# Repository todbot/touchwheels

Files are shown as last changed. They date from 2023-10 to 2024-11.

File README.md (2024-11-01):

# Touchwheels

Some capacitive sense rotary touchwheels.  

These work by using only three capactive touch pads in a specific interleaved 
geometry and measuring the relative ratio of analog capacitive touch values 
between the pads to compute a distance along the slider. 

### Touchwheels made so far:

* TouchWheelSAO -- [Touchwheel SAO as part of  Hackaday Supercon 2024 badge](https://github.com/todbot/TouchwheelSAO)

* touchwheel0 - [available on Tindie as a kit!](https://www.tindie.com/products/todbot/touchwheel0-capacitive-touch-wheel/)

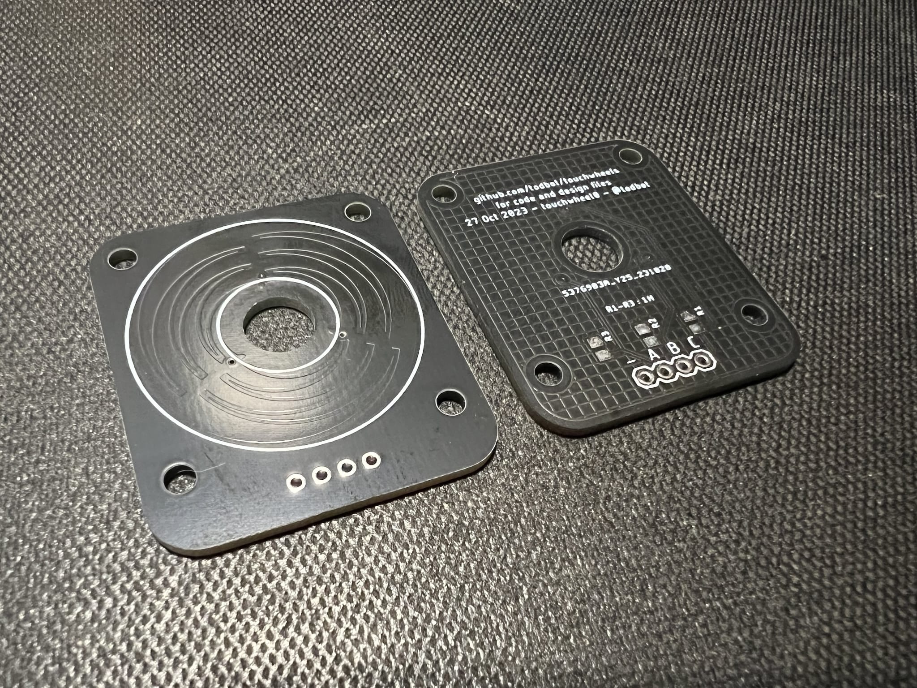
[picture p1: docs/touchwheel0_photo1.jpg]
  
  
  Similar to an iPod's wheel, `touchwheel0` is a 30 mm (0.6") diameter 
  [rotary capacitive touch slider](https://onlinedocs.microchip.com/pr/GUID-A8A0085D-58D1-4E41-A07D-B93BFDE11AFE-en-US-4/index.html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) that can be used with most any microcontroller. It uses three digital GPIO pins and requires no extra components. The included examples in CircuitPython and Arduino show how to turn the raw capacitive touch readings of the three pins into a linear 0-360º angle measurement.

* picoslidertoy - Available at the [picoslidertoy repo](https://github.com/todbot/picoslidertoy)
  
  

### Demos:

There are several examples on how to use the touchwheel:

- [demo0](./circuitpython/demo0/code.py) -
    CircuitPython example showing basic concept on touchwheel0
  
- [touchwheel_badgedemo](./circuitpython/touchwheel_badgedemo/code.py) - 
    CircuitPython example for the Hackaday SuperCon 2023 badge (where touchwheel0 PCBs were given away)
    
- [demo_dual](./circuitpython/demo_dual/code.py) - 
    CircuitPython example show two touchwheel0s in use

- more demos coming!

### What's in Tindie touchwheel0 kit: 

The [touchwheel0 kit](https://www.tindie.com/products/todbot/touchwheel0-capacitive-touch-wheel/)
on Tindie comes with:

- touchwheel0 black PCB
- 4 x 1M 0805 SMD resistors (only three needed, one is a spare)
- 1 x 4-pin pin header 

It makes a pretty good "first SMD soldering" exercise as the 0805 resistors 
are relatively big and not very heat sensitive. 

### Demo videos:

- demo dual:
  [(click to view on youtube)](https://www.youtube.com/watch?v=Db7S75eE-G8)

  [](https://www.youtube.com/watch?v=Db7S75eE-G8 "touchwheel0 dual demo")

- demo0: 

  https://github.com/todbot/touchwheels/assets/274093/fc2b794f-5dff-42b4-8942-f141de19e4ab

### Useful links:

- [AN2934 - Capacitive Touch Sensor Design Guide (pdf)](https://ww1.microchip.com/downloads/en/Appnotes/Capacitive-Touch-Sensor-Design-Guide-DS00002934-B.pdf)
- [QTAN007 - Buttons, Sliders and Wheels - Sensor Design Guide (pdf)](https://www.mouser.com/pdfDocs/QTouch_QTAN0079.pdf)
- [AT02259: QTouch Schematic and Layout Checklist (pdf)](http://ww1.microchip.com/downloads/en/appnotes/atmel-42094-qtouch-schematic-and-layout-checklist_applicationnote_at02259.pdf)
- [slider generator](https://cooltech.zone/tangara/labs/touchwheel-electrode-tool/)
- [SLAA891B: Automating Capacitive Touch Sensor PCB layouts with OpenSCAD Ti AppNote (pdf)](https://www.ti.com/lit/an/slaa891b/slaa891b.pdf?ts=1725369981627)

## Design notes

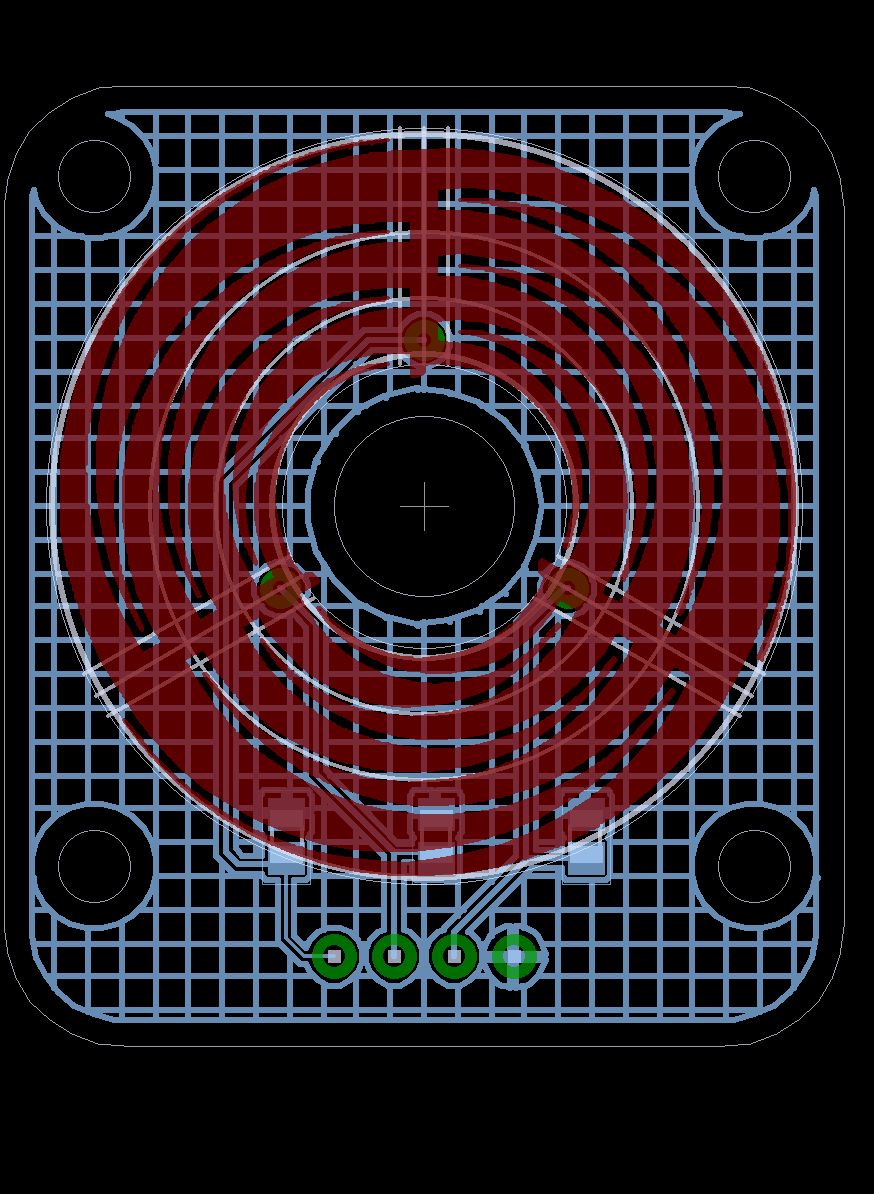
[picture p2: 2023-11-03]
hardware/touchwheel0/touchwheel0_pcb.png

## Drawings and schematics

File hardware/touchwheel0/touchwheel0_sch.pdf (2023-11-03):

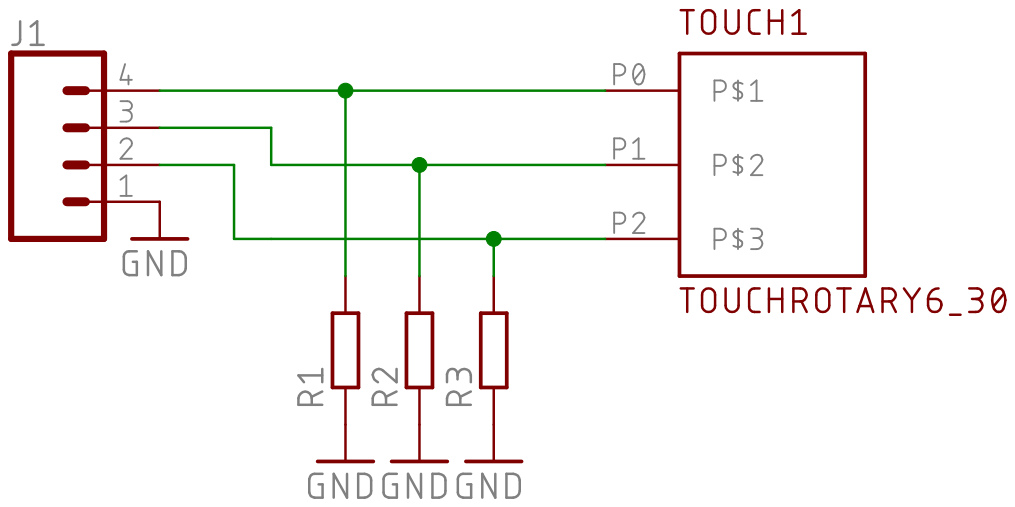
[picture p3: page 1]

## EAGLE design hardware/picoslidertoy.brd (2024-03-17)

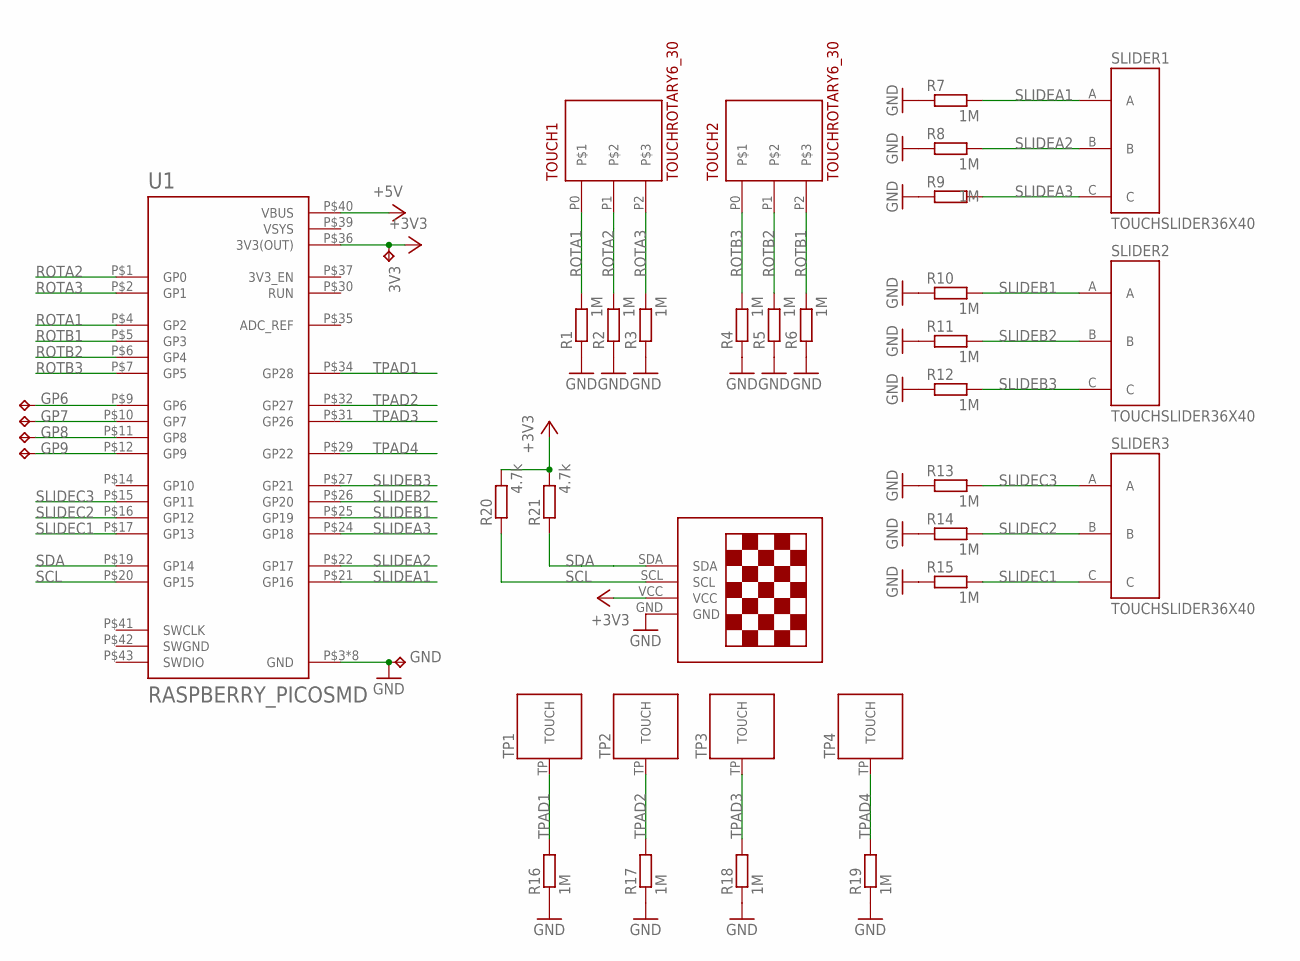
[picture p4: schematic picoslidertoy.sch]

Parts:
3V3: TPTP20R; TP20R
GND: TPTP20R; TP20R
GP6, GP7, GP8, GP9: TPTP20R; TP20R
R1, R2, R3, R4, R5, R6, R7, R8, R9, R10, R11, R12, R13, R14, R15, R16, R17, R18, R19: 1M; R0805
R20, R21: 4.7k; R0805
SLIDER1, SLIDER2, SLIDER3: TOUCHSLIDER36X40; TOUCHSLIDER3_6X40
SMDBACK2: 13"OLEDSMDONLY; 1.3"OLED_SMDBACKONLY
TOUCH1, TOUCH2: TOUCHROTARY6_30; TOUCHROTARY1B
TP1, TP2, TP3, TP4: TOUCHPADA; TOUCHPADA_0.5IN
U1: RASPBERRY_PICOSMD; PICO-PKG-SMD

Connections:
+3V3: 3V3.TP, R20.2, R21.2, SMDBACK2.VCC, U1.P$36 (3V3(OUT))
+5V: U1.P$40 (VBUS)
GND: GND.TP, R1.1, R2.1, R3.1, R4.1, R5.1, R6.1, R7.1, R8.1, R9.1, R10.1, R11.1, R12.1, R13.1, R14.1, R15.1, R16.1, R17.1, R18.1, R19.1, SMDBACK2.GND, U1.P$3 (GND), U1.P$8 (GND), U1.P$13 (GND), U1.P$18 (GND), U1.P$23 (GND), U1.P$28 (GND), U1.P$33 (GND), U1.P$38 (GND)
unnamed: GP6.TP, U1.P$9 (GP6)
unnamed: GP7.TP, U1.P$10 (GP7)
unnamed: GP9.TP, U1.P$12 (GP9)
unnamed: GP8.TP, U1.P$11 (GP8)
ROTA1: R1.2, TOUCH1.P0, U1.P$4 (GP2)
ROTA2: R2.2, TOUCH1.P1, U1.P$1 (GP0)
ROTA3: R3.2, TOUCH1.P2, U1.P$2 (GP1)
ROTB1: R6.2, TOUCH2.P2, U1.P$5 (GP3)
ROTB2: R5.2, TOUCH2.P1, U1.P$6 (GP4)
ROTB3: R4.2, TOUCH2.P0, U1.P$7 (GP5)
SCL: R20.1, SMDBACK2.SCL, U1.P$20 (GP15)
SDA: R21.1, SMDBACK2.SDA, U1.P$19 (GP14)
SLIDEA1: R7.2, SLIDER1.A, U1.P$21 (GP16)
SLIDEA2: R8.2, SLIDER1.B, U1.P$22 (GP17)
SLIDEA3: R9.2, SLIDER1.C, U1.P$24 (GP18)
SLIDEB1: R10.2, SLIDER2.A, U1.P$25 (GP19)
SLIDEB2: R11.2, SLIDER2.B, U1.P$26 (GP20)
SLIDEB3: R12.2, SLIDER2.C, U1.P$27 (GP21)
SLIDEC1: R15.2, SLIDER3.C, U1.P$17 (GP13)
SLIDEC2: R14.2, SLIDER3.B, U1.P$16 (GP12)
SLIDEC3: R13.2, SLIDER3.A, U1.P$15 (GP11)
SWGND: U1.P$42 (SWGND)
TPAD1: R16.2, TP1.TP, U1.P$34 (GP28)
TPAD2: R17.2, TP2.TP, U1.P$32 (GP27)
TPAD3: R18.2, TP3.TP, U1.P$31 (GP26)
TPAD4: R19.2, TP4.TP, U1.P$29 (GP22)
VSYS: U1.P$39 (VSYS)

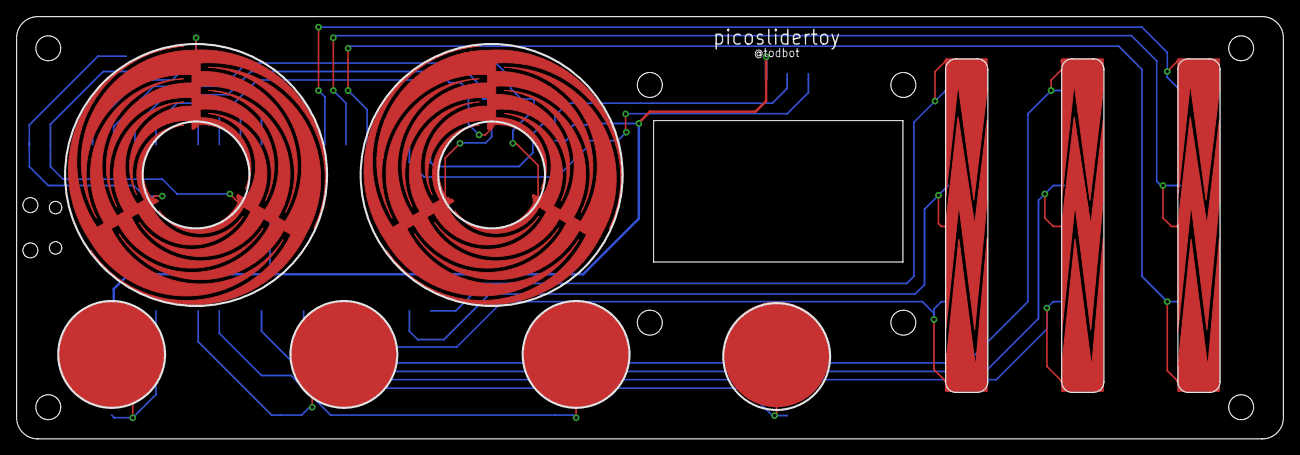
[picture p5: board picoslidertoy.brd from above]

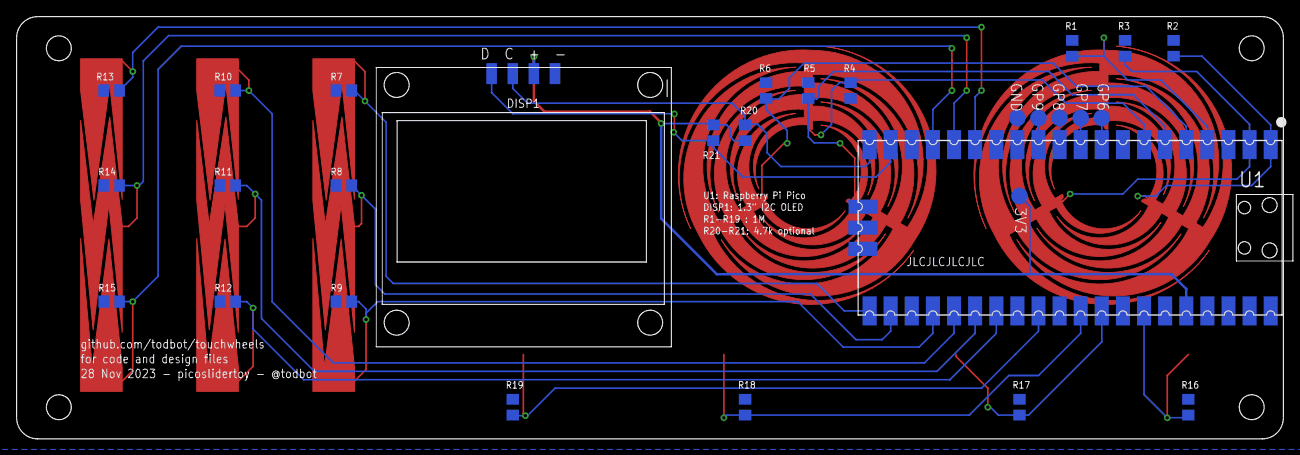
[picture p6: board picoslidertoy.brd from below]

Board: 2 copper layers, 152.4 x 50.8 mm, 38 parts (28 on the bottom side), 27 nets.

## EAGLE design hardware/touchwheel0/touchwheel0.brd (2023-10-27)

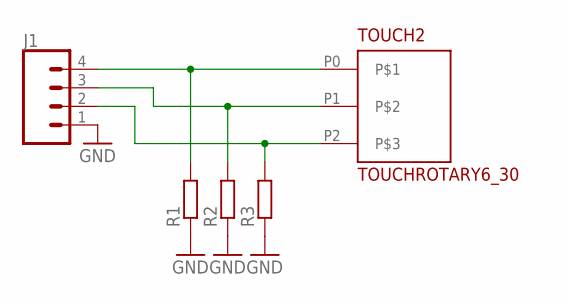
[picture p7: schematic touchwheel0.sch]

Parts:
J1: CONN_04; 1X04
R1, R2, R3: R-EU_R0805; R0805
TOUCH2: TOUCHROTARY6_30; TOUCHROTARY1B

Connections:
GND: J1.1, R1.1, R2.1, R3.1
unnamed: J1.4, R1.2, TOUCH2.P0
unnamed: J1.3, R2.2, TOUCH2.P1
unnamed: J1.2, R3.2, TOUCH2.P2

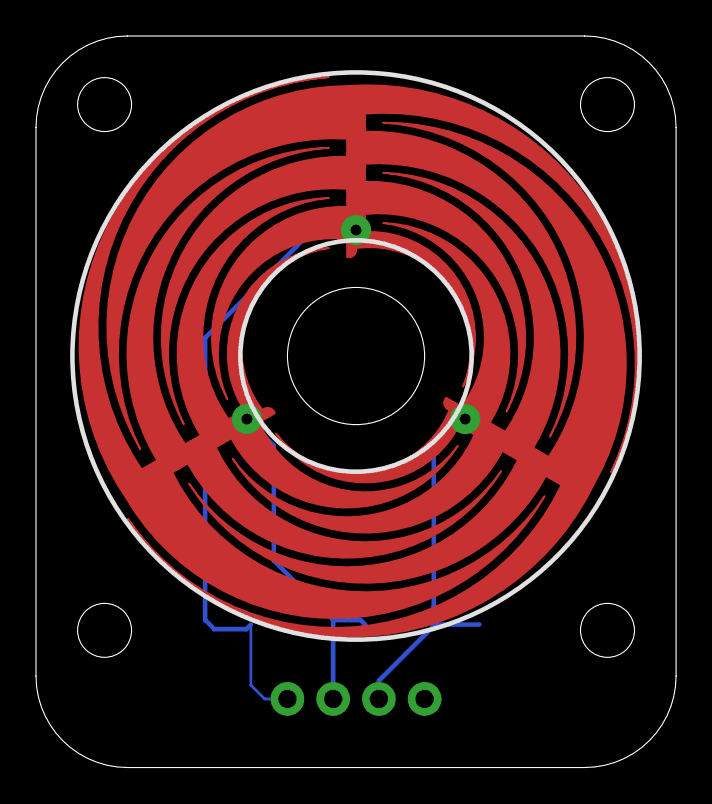
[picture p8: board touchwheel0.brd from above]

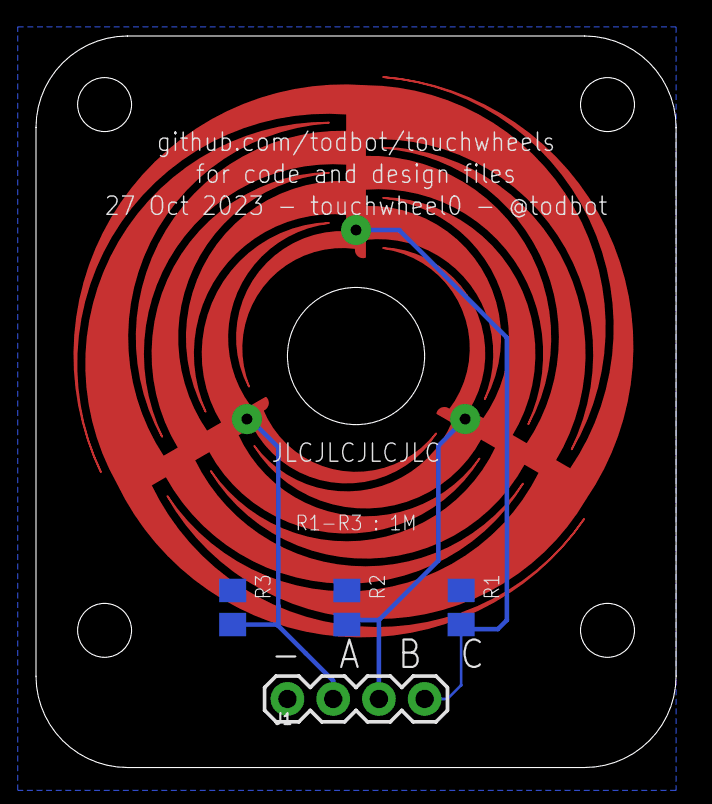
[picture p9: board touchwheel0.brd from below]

Board: 2 copper layers, 35.6 x 40.6 mm, 5 parts (4 on the bottom side), 4 nets.

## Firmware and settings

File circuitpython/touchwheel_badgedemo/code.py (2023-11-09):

# touchwheel_badgedemo.py -- try out touchwheel on Supercon2023 badge in CircuitPython
# 5 Nov 2023 - @todbot / Tod Kurt
#  originally from github.com/todbot/HackadayVectorscopeHacks
#
import time, math
import board
import touchio

# touchwheel plugged into GND,GP26,GP27,GP28 on side of Supercon2023 badge
touch_pins = (board.GP26, board.GP27, board.GP28)

class TouchWheel():
    """Simple capacitive touchweel made from three captouch pads """
    def __init__(self,touch_pins, offset=-0.333/2):
        self.touchins = []
        self.offset = offset # physical design is rotated 1/2 a sector anti-clockwise
        for p in touch_pins:
            touchin = touchio.TouchIn(p)
            self.touchins.append(touchin)

    def pos(self):
        """
        Given three touchio.TouchIn pads, compute wheel position 0-1
        or return None if wheel is not pressed
        """
        a = self.touchins[0]
        b = self.touchins[1]
        c = self.touchins[2]

        # compute raw percentages
        a_pct = (a.raw_value - a.threshold) / a.threshold
        b_pct = (b.raw_value - b.threshold) / b.threshold
        c_pct = (c.raw_value - c.threshold) / c.threshold
        #print( "%+1.2f  %+1.2f  %+1.2f" % (a_pct, b_pct, c_pct), end="\t")

        pos = None
        # cases when finger is touching two pads
        if a_pct >= 0 and b_pct >= 0:  #
            pos = 0 + 0.333 * (b_pct / (a_pct + b_pct))
        elif b_pct >= 0 and c_pct >= 0:  #
            pos = 0.333 + 0.333 * (c_pct / (b_pct + c_pct))
        elif c_pct >= 0 and a_pct >= 0:  #
            pos = 0.666 + 0.333 * (a_pct / (c_pct + a_pct))
        # special cases when finger is just on a single pad.
        elif a_pct > 0 and b_pct <= 0 and c_pct <= 0:
            pos = 0
        elif a_pct <= 0 and b_pct > 0 and c_pct <= 0:
            pos = 0.333
        elif a_pct <= 0 and b_pct <= 0 and c_pct > 0:
            pos = 0.666
        # wrap pos around the 0-1 circle if offset puts it outside that range
        return (pos + self.offset) % 1 if pos is not None else None


touchwheel = TouchWheel(touch_pins)

while True:
    pos = touchwheel.pos()
    if pos is not None:   # touched!
        print("touch_pos:", pos)
    else:
        print("no touch")
    time.sleep(0.05)

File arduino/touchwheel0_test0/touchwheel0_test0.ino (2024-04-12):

// touchwheel0_test0.ino -- initial demonstration of touchwheel on Arduino, needs work still
// 2 Apr 2024 - @todbot / Tod Kurt

#include "TouchyTouch.h"

const int touch_pins[] = {11, 12, 13, };
const int touch_count = 3; 

TouchyTouch touches[touch_count];

/**
 * Given three touchio.TouchIn pads, compute wheel position 0-1
 * or return -1 if wheel is not pressed
 */
float wheel_pos() { 
  // compute raw percentages
  float a_pct = ((float)touches[0].raw_value - touches[0].threshold) / touches[0].threshold;
  float b_pct = ((float)touches[1].raw_value - touches[1].threshold) / touches[1].threshold;
  float c_pct = ((float)touches[2].raw_value - touches[2].threshold) / touches[2].threshold;
  Serial.printf("\t\t\t%+1.2f  %+1.2f  %+1.2f\n", a_pct, b_pct, c_pct);

  float offset = -0.333/2;  // physical design is rotated 1/2 a sector anti-clockwise

  float pos = -1;
  //cases when finger is touching two pads
  if( a_pct >= 0 and b_pct >= 0 ) {
      pos = 0 + 0.333 * (b_pct / (a_pct + b_pct));
  } 
  else if( b_pct >= 0 and c_pct >= 0 ) {
      pos = 0.333 + 0.333 * (c_pct / (b_pct + c_pct));
  }
  else if( c_pct >= 0 and a_pct >= 0 ) { 
      pos = 0.666 + 0.333 * (a_pct / (c_pct + a_pct));
  }
  // special cases when finger is just on a single pad.
  // these shouldn't be needed and create "deadzones" at these points
  // so surely there's a better solution
  else if( a_pct > 0 and b_pct <= 0 and c_pct <= 0 ) { 
      pos = 0;
  }
  else if( a_pct <= 0 and b_pct > 0 and c_pct <= 0 ) { 
      pos = 0.333;
  }
  else if( a_pct <= 0 and b_pct <= 0 and c_pct > 0 ) {
      pos = 0.666;
  }
  if( pos == -1 ) { // no touch 
    return -1;
  }
  // wrap pos around the 0-1 circle if offset puts it outside that range
  return fmod(pos + offset, 1);
}

void setup() {
  Serial.begin(115200);
  Serial.println("TouchyTouch touchwheel test0");

  pinMode(LED_BUILTIN, OUTPUT);

  // Touch buttons
  for (int i = 0; i < touch_count; i++) {
    touches[i].begin( touch_pins[i] );
  }

}

void loop() {
  for ( int i = 0; i < touch_count; i++) {
    touches[i].update();
  }

  // Serial.printf("raw/thresh %d/%d  %d/%d  %d/%d\n", 
  //                 touches[0].raw_value, touches[0].threshold,
  //                 touches[1].raw_value, touches[1].threshold,
  //                 touches[2].raw_value, touches[2].threshold);

  float pos = wheel_pos();
  Serial.printf("%ld: Pos: %.2f\n", millis(), pos);

  delay(50);
  digitalWrite(LED_BUILTIN, LOW);
}

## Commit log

2023-11-03 png of pcb
2023-12-04 should finally commit picosolidertoy
    [picoslidertoy.brd, picoslidertoy.sch]
2023-12-06 picoslidertoy layout mostly done
    [picoslidertoy.brd]
2024-03-17 old picoslidertoy sync up, but moved dev to its own repo and kicad
    [picoslidertoy.brd, picoslidertoy.sch]
2024-03-23 moved old picoslidertoy idea, new version has its own repo
    [picoslidertoy.brd, picoslidertoy.sch]
2024-04-12 add dual touchwheel0 example
    [picoslidertoy.brd, picoslidertoy.sch]
2024-04-12 check in start of arduino version

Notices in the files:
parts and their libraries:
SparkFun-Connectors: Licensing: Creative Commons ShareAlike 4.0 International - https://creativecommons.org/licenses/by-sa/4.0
